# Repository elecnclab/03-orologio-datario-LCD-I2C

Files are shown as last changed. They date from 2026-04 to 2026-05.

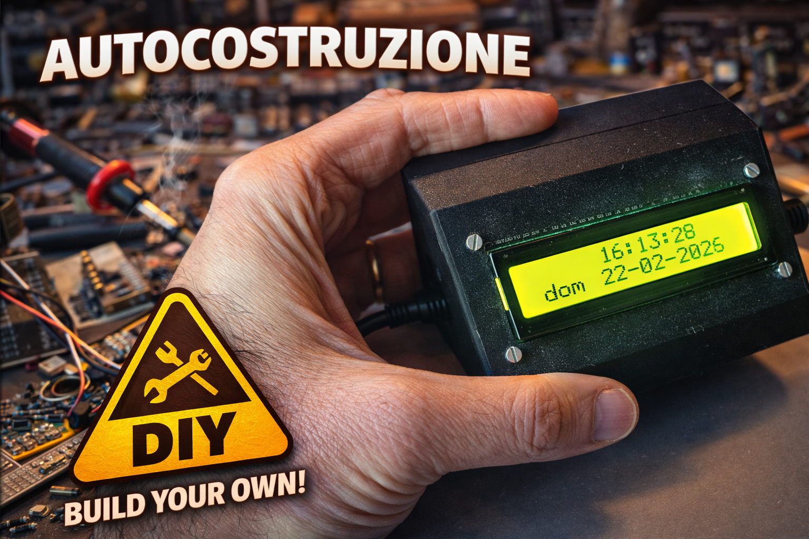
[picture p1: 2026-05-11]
media/foto/miniatura-1.png

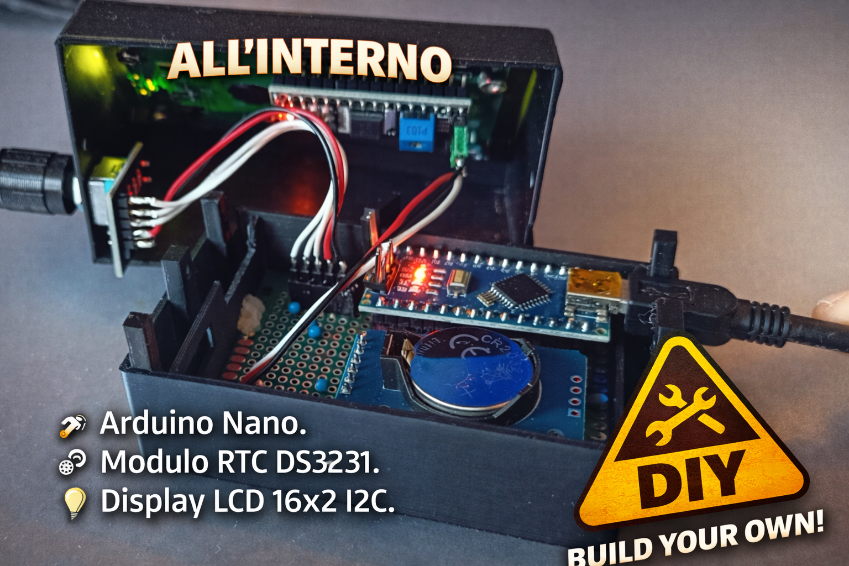
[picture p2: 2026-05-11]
media/foto/miniatura-2.png

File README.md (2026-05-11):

# 03-orologio-datario-LCD-I2C

Orologio digitale multifunzione con datario, timer countdown, cronometro e sveglia giornaliera.
Il progetto usa `Arduino Nano`, `RTC DS3231`, `LCD 16x2 I2C`, encoder rotativo (`KY-040`) e buzzer attivo LOW.

Video demo: https://youtu.be/ws_6DP3VXj8

## Caratteristiche principali

- Visualizzazione ora (`HH:MM:SS`) con allineamento configurabile (`SX`, `CTR`, `DX`)
- Datario con giorno settimana in italiano (`dom`...`sab`)
- Impostazione ora e data da menu
- Timer countdown (`00:00:00` a `99:59:59`) con pausa/riprendi
- Cronometro con visualizzazione `MM:SS:CC`
- Sveglia giornaliera basata su interrupt hardware DS3231 (pin `INT/SQW`)
- Parametri persistenti in EEPROM:
  - retroilluminazione LCD
  - allineamento ora
  - stato sveglia e orario sveglia

## Hardware

- Arduino Nano (ATmega328P)
- Modulo RTC DS3231
- Display LCD 16x2 con backpack I2C (indirizzo firmware: `0x27`)
- Encoder rotativo KY-040 con pulsante integrato
- Buzzer attivo LOW

## Collegamenti

### Encoder KY-040

- `CLK` -> `D4`
- `DT` -> `D3`
- `SW` -> `D2`
- `+` -> `5V`
- `GND` -> `GND`

### Bus I2C (LCD + DS3231)

- `SDA` -> `A4`
- `SCL` -> `A5`
- `VCC` -> `5V`
- `GND` -> `GND`

### Buzzer attivo LOW

- `IN` -> `D6`
- `GND` -> `GND`

### Interrupt sveglia DS3231

- `INT/SQW` -> `D7`

## Librerie Arduino usate

- `Wire.h`
- `RTClib.h`
- `LiquidCrystal_I2C.h`
- `EEPROM.h`

## Struttura repository

- `.github/`
- `firmware/03-orologio-datario-LCD-I2C/03-orologio-datario-LCD-I2C.ino`
- `docs/bom/`
- `docs/schemi/`
- `docs/note-tecniche/`
- `media/foto/`
- `media/github-images/`
- `hardware/stl/`
- `CHANGELOG.md`
- `VERSION`

## Media

- Foto progetto: `media/foto/miniatura-1.png`, `media/foto/miniatura-2.png`
- Immagini per README/GitHub: `media/github-images/`

## File STL

- `hardware/stl/base-orologio.stl`
- `hardware/stl/front-orologio.stl`

## Compilazione e upload

1. Apri lo sketch in Arduino IDE:
   - `firmware/03-orologio-datario-LCD-I2C/03-orologio-datario-LCD-I2C.ino`
2. Verifica/installa le librerie richieste.
3. Se necessario, adatta:
   - indirizzo I2C LCD (`LCD_ADDR`, default `0x27`)
   - verso encoder (`ENCODER_DIRECTION`, default `+1`)
4. Seleziona scheda e porta corrette.
5. Compila e carica.

## Uso rapido interfaccia

- **RUN (schermata normale)**
  - Rotazione encoder: apre `PARAM/INFO`
  - Pressione lunga: apre `MENU` principale

- **MENU principale**
  - Voci: `ORA`, `DATA`, `TIMER`, `SVEGLIA`, `CRONOMETRO`
  - Rotazione: cambia voce
  - Click: entra/modifica
  - Pressione lunga: ritorna a `RUN`

Per il dettaglio completo della logica stati e comandi:
- `docs/note-tecniche/architettura-firmware.md`
- `docs/note-tecniche/mappa-menu-e-comandi.md`

## Note operative

- Alla prima accensione, se RTC ha perso alimentazione, l'orario viene impostato alla data/ora di compilazione firmware.
- La riga data su LCD mostra 15 caratteri + icona campanella (se sveglia attiva) nell'ultimo carattere.
- Nel menu `PARAM/INFO` la voce `RESET SETTINGS` e' presente ma non implementata (volutamente lasciata vuota nel firmware attuale).

## Stato progetto

Firmware funzionante e testato fisicamente su hardware reale.
Documentazione tecnica in aggiornamento incrementale in `docs/note-tecniche/`.

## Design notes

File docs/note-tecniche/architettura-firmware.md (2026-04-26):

# Architettura firmware

## Panoramica

Il firmware e' implementato come macchina a stati finiti (`enum Mode`) con loop non bloccante.
Le funzionalita' principali convivono senza `delay()` operativo (tranne splash iniziale), usando `millis()` per refresh display, blink campi e gestione buzzer.

File sorgente:
- `firmware/03-orologio-datario-LCD-I2C/03-orologio-datario-LCD-I2C.ino`

## Moduli logici principali

- **RTC DS3231**
  - lettura data/ora corrente (`rtc.now()`)
  - set ora/data (`rtc.adjust(...)`)
  - gestione sveglia giornaliera con Alarm1

- **Display LCD 16x2 I2C**
  - rendering pagine UI per ogni stato
  - buffering per ridurre sfarfallio (`lcdPrintLineBuffered`)
  - carattere custom campanella in posizione finale riga 2

- **Input encoder + pulsante**
  - quadratura encoder con interrupt `PCINT2_vect` su D3/D4
  - accumulo delta e riduzione rumore tramite `readEncDeltaAtomic()`
  - eventi pulsante: click corto / pressione lunga (`LONG_PRESS_MS = 1000`)

- **Buzzer attivo LOW**
  - beep non bloccante con timeout (`buzzerStart`, `buzzerUpdate`)
  - sequenza sveglia con lampeggio retroilluminazione (`alarmBeepSequenceUpdate`)

- **Persistenza EEPROM**
  - inizializzazione con magic byte (`0xA5`)
  - salvataggio impostazioni utente e sveglia

## Macchina a stati (`Mode`)

Stati definiti:
- `RUN`
- `MENU`
- `SET_TIME`
- `SET_DATE`
- `SET_TIMER`
- `TIMER_RUNNING`
- `PARAM_MENU`
- `ALARM_MENU`
- `SET_ALARM`
- `STOPWATCH_RUNNING`

Approccio:
- ogni stato gestisce input (`step`, `evtShortClick`, `evtLongPress`)
- rendering periodico vincolato da `REFRESH_MS`
- transizioni esplicite tramite funzioni `enter...()`

## Temporizzazioni principali

- `REFRESH_MS = 120` ms: refresh display/UI
- `BLINK_MS = 350` ms: lampeggio campo in edit
- `PARAM_TIMEOUT_MS = 8000` ms: uscita automatica da `PARAM_MENU`
- `LONG_PRESS_MS = 1000` ms: soglia pressione lunga pulsante encoder

## Gestione sveglia DS3231

- Il pin `INT/SQW` del DS3231 e' collegato a `D7` (`ALARM_PIN`).
- In setup:
  - disattivazione square wave
  - pulizia flag allarmi
  - programmazione Alarm1 giornaliera su `alarmHour:alarmMin:00`
- In loop:
  - polling livello pin (`LOW` = evento sveglia)
  - avvio sequenza beep
  - clear flag Alarm1

## Timer countdown

- Set da menu (`HH:MM:SS`, max 99 ore)
- Start solo se durata > 0
- In esecuzione:
  - click corto: pausa/riprendi
  - pressione lunga: stop/uscita
- A fine timer:
  - beep 500 ms
  - messaggio `TIMER SCADUTO` per circa 2 s

## Cronometro

- Base tempo: `millis()`
- Stati logici: fermo / running / pausa
- Click corto: start-pause-resume
- Pressione lunga: reset + uscita a `RUN`
- Formato visualizzato: `MM:SS:CC`

## EEPROM: mappa indirizzi

- `0`: magic byte
- `1`: backlight (`0/1`)
- `2`: allineamento orario (`0..2`)
- `3`: sveglia abilitata (`0/1`)
- `4`: ora sveglia (`0..23`)
- `5`: minuti sveglia (`0..59`)

Nota: la voce `RESET SETTINGS` e' prevista in UI ma la logica e' volutamente non implementata nel firmware attuale.

## Pinout firmware (riepilogo)

- Encoder `CLK` -> `D4`
- Encoder `DT` -> `D3`
- Encoder `SW` -> `D2`
- Buzzer -> `D6` (attivo LOW)
- DS3231 `INT/SQW` -> `D7`
- I2C -> `A4 SDA`, `A5 SCL`

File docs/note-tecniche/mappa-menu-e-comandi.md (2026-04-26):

# Mappa menu e comandi encoder

Questa nota descrive il comportamento dell'interfaccia utente nel firmware attuale.

## Convenzioni input

- **Rotazione encoder**: incrementa/decrementa valore o selezione menu
- **Click corto**: conferma / entra nel campo successivo / toggle funzione
- **Pressione lunga** (~1 s): uscita o ritorno al livello precedente

## Stato RUN

Schermata standard:
- Riga 1: ora (`HH:MM:SS`) con allineamento configurabile
- Riga 2: `giorno dd-mm-yyyy` + campanella se sveglia attiva

Comandi:
- Rotazione -> entra in `PARAM_MENU`
- Pressione lunga -> entra in `MENU`

## MENU principale

Voci in ordine:
1. `ORA`
2. `DATA`
3. `TIMER`
4. `SVEGLIA`
5. `CRONOMETRO`

Comandi:
- Rotazione -> cambia voce
- Click corto -> entra nella voce selezionata
- Pressione lunga -> ritorna a `RUN`

## SET ORA (`SET_TIME`)

Campi editabili in sequenza:
1. ore
2. minuti
3. secondi

Comandi:
- Rotazione -> modifica campo corrente (con wrap)
- Click corto -> campo successivo; sull'ultimo campo salva su RTC e torna a `RUN`
- Pressione lunga -> annulla/uscita a `RUN`

## SET DATA (`SET_DATE`)

Campi editabili in sequenza:
1. giorno
2. mese
3. anno (2000..2099)

Comandi:
- Rotazione -> modifica campo corrente (con wrap)
- Click corto -> campo successivo; sull'ultimo campo salva su RTC e torna a `RUN`
- Pressione lunga -> annulla/uscita a `RUN`

Note:
- I limiti del giorno sono coerenti con mese/anno (anni bisestili inclusi).

## SET TIMER (`SET_TIMER`)

Campi editabili in sequenza:
1. ore (0..99)
2. minuti (0..59)
3. secondi (0..59)

Comandi:
- Rotazione -> modifica campo corrente
- Click corto -> campo successivo; sull'ultimo campo avvia countdown (se diverso da zero)
- Pressione lunga -> uscita a `RUN`

## TIMER in esecuzione (`TIMER_RUNNING`)

Visualizzazione:
- Riga 1: orario corrente
- Riga 2: `TIMER HH:MM:SS` oppure `PAUSA HH:MM:SS`

Comandi:
- Click corto -> pausa/riprendi
- Pressione lunga -> stop timer e ritorno a `RUN`

Fine timer:
- beep breve
- messaggio `TIMER SCADUTO`
- ritorno automatico a `RUN`

## Menu parametri/info (`PARAM_MENU`)

Accesso da `RUN` ruotando l'encoder.
Timeout automatico: circa 8 s senza azioni.

Voci:
1. `BACKLIGHT: ON/OFF` (toggle + salvataggio EEPROM)
2. `ORARIO: SX/CTR/DX` (ciclo + salvataggio EEPROM)
3. `TEST BUZZER` (beep 1 s)
4. `INFO FW` (pagina info)
5. `RESET SETTINGS` (placeholder non attivo)

Comandi:
- Rotazione -> cambia voce
- Click corto -> esegue azione voce
- Pressione lunga -> ritorna a `RUN`

In `INFO FW`:
- Click corto o pressione lunga -> ritorno a lista `PARAM_MENU`

## Menu sveglia (`ALARM_MENU`)

Voci:
1. `ATTIVA: ON/OFF`
2. `ORA: HH:MM`

Comandi:
- Rotazione -> seleziona voce
- Click corto su `ATTIVA` -> toggle + salva EEPROM + riprogramma DS3231
- Click corto su `ORA` -> entra in `SET_ALARM`
- Pressione lunga -> ritorna a `RUN`

## SET SVEGLIA (`SET_ALARM`)

Campi editabili:
1. ore
2. minuti

Comandi:
- Rotazione -> modifica campo
- Click corto -> passa al campo successivo; a fine sequenza salva e torna a `ALARM_MENU`
- Pressione lunga -> ritorna a `ALARM_MENU` senza conferma finale

## CRONOMETRO (`STOPWATCH_RUNNING`)

Visualizzazione:
- Riga 1: orario corrente
- Riga 2: `CRONO MM:SS:CC` oppure `PAUSA MM:SS:CC`

Comandi:
- Click corto -> start/pause/resume
- Pressione lunga -> reset cronometro e ritorno a `RUN`

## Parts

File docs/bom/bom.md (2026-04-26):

# BOM (Bill of Materials)

Elenco componenti principali del progetto `03-orologio-datario-LCD-I2C`.

## Elettronica

| Qta | Componente | Note |
|---|---|---|
| 1 | Arduino Nano (ATmega328P) | Compatibile 5V |
| 1 | RTC DS3231 | Modulo I2C |
| 1 | LCD 16x2 I2C | Backpack tipico PCF8574, indirizzo firmware `0x27` |
| 1 | Encoder KY-040 | Con pulsante integrato |
| 1 | Buzzer attivo LOW | Pilotato da `D6` |

## Cablaggio rapido

- I2C: `A4` (SDA), `A5` (SCL)
- Encoder: `D4` (CLK), `D3` (DT), `D2` (SW)
- Sveglia DS3231: `INT/SQW` su `D7`
- Buzzer: `IN` su `D6`

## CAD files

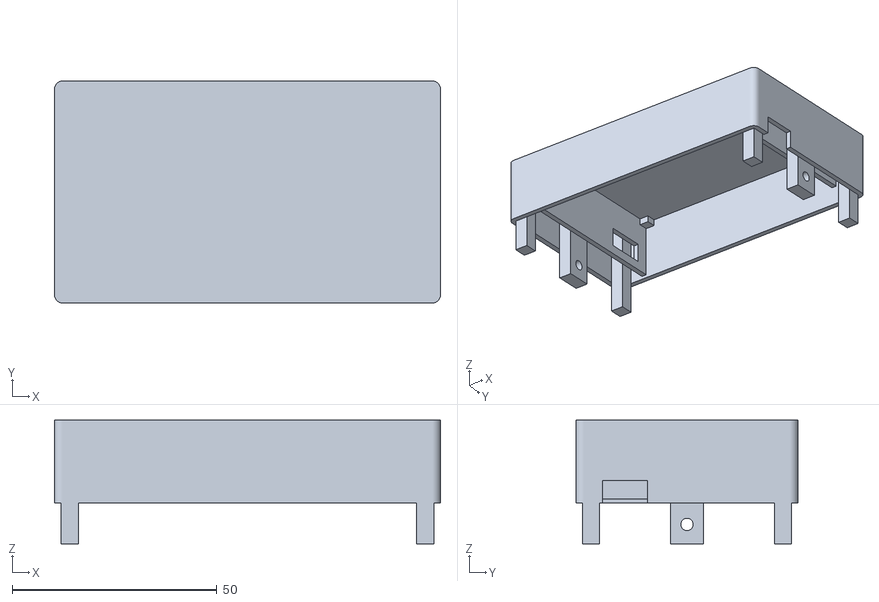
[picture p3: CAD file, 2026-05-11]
hardware/stl/base-orologio.stl
94.2 x 54.2 x 30.2

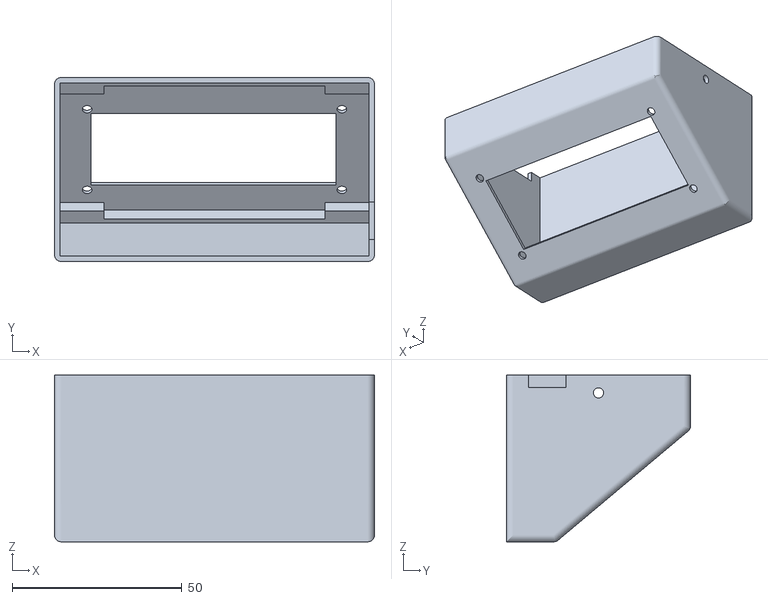
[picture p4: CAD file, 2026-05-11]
hardware/stl/front-orologio.stl
94.2 x 54.2 x 49.0

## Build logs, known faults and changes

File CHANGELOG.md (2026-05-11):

# Changelog

Tutte le modifiche rilevanti a questo progetto sono documentate in questo file.

## [1.0.1] - 2026-05-11

### Added

- File STL:
  - `hardware/stl/base-orologio.stl`
  - `hardware/stl/front-orologio.stl`
- Foto progetto:
  - `media/foto/miniatura-1.png`
  - `media/foto/miniatura-2.png`

### Changed

- `README.md` aggiornato con sezione media e file STL

## [1.0.0] - 2026-04-26

### Added

- Struttura base repository (`firmware`, `docs`, `media`, `hardware`)
- README iniziale
- Note tecniche:
  - architettura firmware
  - mappa menu e comandi encoder
- Sezione `docs/bom/` con BOM iniziale
- Template PR in `.github/pull_request_template.md`

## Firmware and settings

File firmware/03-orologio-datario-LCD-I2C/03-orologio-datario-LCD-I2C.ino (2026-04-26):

/*
   ------------------------------------------------------------
   Orologio Multifuzione con Datario - V2
   Arduino Nano + RTC DS3231 + LCD 16x2 I2C
   ------------------------------------------------------------

   Breve descrizione:
   Orologio digitale multifunzione con visualizzazione di ora,
   data e giorno della settimana, dotato di timer countdown,
   cronometro, sveglia giornaliera e menu di navigazione tramite
   encoder rotativo. Il dispositivo utilizza un modulo RTC
   DS3231 per mantenere l'orario con elevata precisione e un
   buzzer attivo per le segnalazioni acustiche.

   Video del progetto:
   https://youtu.be/ws_6DP3VXj8

   Autore:
   Giuseppe Romano

   Canale YouTube:
   Electronic & CNC Lab
   https://www.youtube.com/@Electronic.CNCLab

   ------------------------------------------------------------
   Progetto realizzato a scopo didattico e divulgativo.
   ------------------------------------------------------------
*/

#include <Wire.h>
#include <RTClib.h>
#include <LiquidCrystal_I2C.h>
#include <EEPROM.h>

/*
  Orologio + Datario + Timer + Sveglia giornaliera
  RTC: DS3231
  LCD: 16x2 I2C
  Encoder: KY-040
  Buzzer: attivo LOW

  Collegamenti:
    Encoder CLK -> D4
    Encoder DT  -> D3
    Encoder SW  -> D2
    Encoder +   -> 5V
    Encoder GND -> GND

    LCD I2C / DS3231:
      SDA -> A4
      SCL -> A5
      VCC -> 5V
      GND -> GND

    Buzzer attivo LOW:
      IN  -> D6
      GND -> GND

    DS3231 INT/SQW -> D7
*/

#define PIN_ENC_CLK 4
#define PIN_ENC_DT 3
#define PIN_ENC_SW 2

#define BUZZER_PIN 6  // buzzer attivo LOW
#define ALARM_PIN 7   // DS3231 INT/SQW -> LOW quando scatta la sveglia

#define LCD_ADDR 0x27
#define LCD_COLS 16
#define LCD_ROWS 2


const unsigned long LONG_PRESS_MS = 1000;
const int ENCODER_DIRECTION = +1;

const unsigned long REFRESH_MS = 120;
const unsigned long BLINK_MS = 350;
const unsigned long PARAM_TIMEOUT_MS = 8000;

bool inInfoFw = false;

RTC_DS3231 rtc;
LiquidCrystal_I2C lcd(LCD_ADDR, LCD_COLS, LCD_ROWS);

const char *giorniITA[7] = { "dom", "lun", "mar", "mer", "gio", "ven", "sab" };

byte bellChar[8] = {
  B00100,
  B01110,
  B01110,
  B01110,
  B11111,
  B00100,
  B00000,
  B00100
};



// ------------------- STATI -------------------
enum Mode {
  RUN,
  MENU,
  SET_TIME,
  SET_DATE,
  SET_TIMER,
  TIMER_RUNNING,
  PARAM_MENU,
  ALARM_MENU,
  SET_ALARM,
  STOPWATCH_RUNNING
};

Mode mode = RUN;

// ------------------- PARAMETRI RUN -------------------
enum TimeAlign : uint8_t { ALIGN_LEFT = 0,
                           ALIGN_CENTER = 1,
                           ALIGN_RIGHT = 2 };
TimeAlign timeAlign = ALIGN_CENTER;

bool backlightEnabled = true;

// ------------------- SVEGLIA -------------------
bool alarmEnabled = false;
uint8_t alarmHour = 7;
uint8_t alarmMin = 30;

// ------------------- TIMER -------------------
uint8_t timerSetH = 0;
uint8_t timerSetM = 0;
uint8_t timerSetS = 0;

bool timerActive = false;
uint32_t timerDurationSec = 0;
unsigned long timerEndMillis = 0;
bool timerBeepDone = false;
unsigned long timerBeepShownAt = 0;
bool timerPaused = false;
uint32_t timerRemainingSec = 0;

// ------------------- CRONOMETRO -------------------
bool stopwatchRunning = false;
bool stopwatchPaused = false;
unsigned long stopwatchStartMillis = 0;
unsigned long stopwatchAccumulatedMs = 0;

// ------------------- MENU INDEX -------------------
int menuIndex = 0;       // MENU principale
int paramIndex = 0;      // PARAM_MENU
int alarmMenuIndex = 0;  // ALARM_MENU

// ------------------- EDITING -------------------
int setHour, setMin, setSec;
int setDay, setMonth, setYear;
int fieldIndex = 0;  // TIME/DATE/TIMER/ALARM

uint8_t setAlarmHour, setAlarmMin;

// ------------------- BLINK -------------------
unsigned long lastBlinkToggle = 0;
bool blinkOn = true;

// ------------------- REFRESH -------------------
unsigned long lastRefresh = 0;
unsigned long paramLastAction = 0;

// ------------------- BUTTON EVENTS -------------------
bool btnPressed = false;
bool btnPrevPressed = false;
unsigned long btnPressStart = 0;
bool longPressFired = false;
bool evtShortClick = false;
bool evtLongPress = false;

// ------------------- ENCODER PCINT -------------------
volatile int16_t encDelta = 0;
volatile uint8_t encPrevPins = 0;

// ------------------- BUZZER NON BLOCCANTE -------------------
bool buzzerActive = false;
unsigned long buzzerOffAt = 0;
bool alarmBeepSequenceActive = false;
uint8_t alarmBeepCount = 0;
bool alarmBeepPhaseOn = false;
unsigned long alarmBeepNextMs = 0;

// ------------------- EEPROM -------------------
const int EEPROM_ADDR_MAGIC = 0;
const int EEPROM_ADDR_BACKLIGHT = 1;
const int EEPROM_ADDR_ALIGN = 2;
const int EEPROM_ADDR_ALARM_EN = 3;
const int EEPROM_ADDR_ALARM_HH = 4;
const int EEPROM_ADDR_ALARM_MM = 5;
const uint8_t EEPROM_MAGIC = 0xA5;

// ------------------- UTIL -------------------
String twoDigits(int v) {
  if (v < 10) return "0" + String(v);
  return String(v);
}

void clearLine(uint8_t row) {
  lcd.setCursor(0, row);
  for (int i = 0; i < LCD_COLS; i++) lcd.print(" ");
}

String pad16(const String &s) {
  if ((int)s.length() >= LCD_COLS) return s.substring(0, LCD_COLS);
  String out = s;
  while ((int)out.length() < LCD_COLS) out += ' ';
  return out;
}

String lastLine0 = "";
String lastLine1 = "";

void lcdPrintLineBuffered(uint8_t row, const String &s) {
  String p = pad16(s);

  if (row == 0) {
    if (p == lastLine0) return;
    lastLine0 = p;
  } else {
    if (p == lastLine1) return;
    lastLine1 = p;
  }

  lcd.setCursor(0, row);
  lcd.print(p);
}

int wrapInt(int value, int minV, int maxV) {
  if (value < minV) return maxV;
  if (value > maxV) return minV;
  return value;
}

bool isLeap(int y) {
  return ((y % 4 == 0 && y % 100 != 0) || (y % 400 == 0));
}

int daysInMonth(int y, int m) {
  if (m == 2) return isLeap(y) ? 29 : 28;
  if (m == 4 || m == 6 || m == 9 || m == 11) return 30;
  return 31;
}

void blankRange(String &s, int start, int len) {
  for (int i = 0; i < len; i++) {
    int idx = start + i;
    if (idx >= 0 && idx < (int)s.length()) s.setCharAt(idx, ' ');
  }
}

String onOff(bool v) {
  return v ? "ON" : "OFF";
}

String alignToStr(TimeAlign a) {
  switch (a) {
    case ALIGN_LEFT: return "SX";
    case ALIGN_CENTER: return "CTR";
    case ALIGN_RIGHT: return "DX";
    default: return "SX";
  }
}

void updateBlink() {
  if (millis() - lastBlinkToggle >= BLINK_MS) {
    lastBlinkToggle = millis();
    blinkOn = !blinkOn;
  }
}

void resetBlink() {
  blinkOn = true;
  lastBlinkToggle = millis();
}

// ------------------- EEPROM -------------------
void loadSettingsFromEEPROM() {
  uint8_t magic = EEPROM.read(EEPROM_ADDR_MAGIC);

  if (magic != EEPROM_MAGIC) {
    backlightEnabled = true;
    timeAlign = ALIGN_CENTER;
    alarmEnabled = false;
    alarmHour = 7;
    alarmMin = 30;

    EEPROM.update(EEPROM_ADDR_MAGIC, EEPROM_MAGIC);
    EEPROM.update(EEPROM_ADDR_BACKLIGHT, (uint8_t)backlightEnabled);
    EEPROM.update(EEPROM_ADDR_ALIGN, (uint8_t)timeAlign);
    EEPROM.update(EEPROM_ADDR_ALARM_EN, (uint8_t)alarmEnabled);
    EEPROM.update(EEPROM_ADDR_ALARM_HH, alarmHour);
    EEPROM.update(EEPROM_ADDR_ALARM_MM, alarmMin);
    return;
  }

  backlightEnabled = (EEPROM.read(EEPROM_ADDR_BACKLIGHT) != 0);

  uint8_t a = EEPROM.read(EEPROM_ADDR_ALIGN);
  if (a > ALIGN_RIGHT) a = ALIGN_LEFT;
  timeAlign = (TimeAlign)a;

  alarmEnabled = (EEPROM.read(EEPROM_ADDR_ALARM_EN) != 0);
  alarmHour = EEPROM.read(EEPROM_ADDR_ALARM_HH);
  alarmMin = EEPROM.read(EEPROM_ADDR_ALARM_MM);

  if (alarmHour > 23) alarmHour = 7;
  if (alarmMin > 59) alarmMin = 30;
}

void saveSettingsToEEPROM() {
  EEPROM.update(EEPROM_ADDR_MAGIC, EEPROM_MAGIC);
  EEPROM.update(EEPROM_ADDR_BACKLIGHT, (uint8_t)backlightEnabled);
  EEPROM.update(EEPROM_ADDR_ALIGN, (uint8_t)timeAlign);
  EEPROM.update(EEPROM_ADDR_ALARM_EN, (uint8_t)alarmEnabled);
  EEPROM.update(EEPROM_ADDR_ALARM_HH, alarmHour);
  EEPROM.update(EEPROM_ADDR_ALARM_MM, alarmMin);
}

// ------------------- BACKLIGHT -------------------
void applyBacklight() {
  if (backlightEnabled) lcd.backlight();
  else lcd.noBacklight();
}

void setBacklightRaw(bool on) {
  if (on) lcd.backlight();
  else lcd.noBacklight();
}
// ------------------- BUZZER -------------------
void alarmBeepSequenceUpdate() {
  if (!alarmBeepSequenceActive) return;

  if ((long)(millis() - alarmBeepNextMs) < 0) return;

  if (!alarmBeepPhaseOn) {
    // Inizio beep
    digitalWrite(BUZZER_PIN, LOW);  // buzzer attivo LOW

    // Lampeggio display in sincronia col beep:
    // inverte lo stato normale della retroilluminazione
    setBacklightRaw(!backlightEnabled);

    alarmBeepPhaseOn = true;
    alarmBeepNextMs = millis() + 300;  // beep ON per 300 ms
  } else {
    // Fine beep
    digitalWrite(BUZZER_PIN, HIGH);  // buzzer spento

    // Ripristina lo stato normale impostato dall'utente
    applyBacklight();

    alarmBeepPhaseOn = false;
    alarmBeepCount++;

    if (alarmBeepCount >= 5) {
      alarmBeepSequenceActive = false;

      // Sicurezza finale: ripristina la retroilluminazione corretta
      applyBacklight();
    } else {
      alarmBeepNextMs = millis() + 300;  // pausa 300 ms
    }
  }
}

void buzzerStart(unsigned long durationMs) {
  digitalWrite(BUZZER_PIN, LOW);  // attivo LOW
  buzzerActive = true;
  buzzerOffAt = millis() + durationMs;
}

void buzzerUpdate() {
  if (buzzerActive && (long)(millis() - buzzerOffAt) >= 0) {
    digitalWrite(BUZZER_PIN, HIGH);  // spento
    buzzerActive = false;
  }
}

void beepTimerEnd() {
  buzzerStart(500);
}

void beepAlarmDaily() {
  alarmBeepSequenceActive = true;
  alarmBeepCount = 0;
  alarmBeepPhaseOn = false;
  alarmBeepNextMs = millis();
}

// ------------------- DS3231 ALARM -------------------
void disableDailyAlarmDS3231() {
  rtc.disableAlarm(1);
  rtc.clearAlarm(1);
}

void programDailyAlarmDS3231() {
  // Spegni square wave e pulisci eventuali flag
  rtc.writeSqwPinMode(DS3231_OFF);
  rtc.clearAlarm(1);
  rtc.clearAlarm(2);
  rtc.disableAlarm(1);
  rtc.disableAlarm(2);

  if (!alarmEnabled) return;

  // Alarm1 giornaliera su HH:MM:SS = alarmHour:alarmMin:00
  // Con DS3231_A1_Hour la data viene ignorata, l'orario viene confrontato ogni giorno
  rtc.setAlarm1(
    DateTime(2000, 1, 1, alarmHour, alarmMin, 0),
    DS3231_A1_Hour);

  rtc.clearAlarm(1);
}

void handleAlarmInterruptIfAny() {
  if (!alarmEnabled) return;

  if (digitalRead(ALARM_PIN) == LOW) {
    beepAlarmDaily();
    rtc.clearAlarm(1);
  }
}

// ------------------- DISPLAY -------------------
void showRun() {
  DateTime now = rtc.now();

  String timeStr = twoDigits(now.hour()) + ":" + twoDigits(now.minute()) + ":" + twoDigits(now.second());
  int padLeft = 0;
  if (timeAlign == ALIGN_CENTER) padLeft = (LCD_COLS - 8) / 2;
  else if (timeAlign == ALIGN_RIGHT) padLeft = (LCD_COLS - 8);

  String r1 = "";
  for (int i = 0; i < padLeft; i++) r1 += " ";
  r1 += timeStr;

  int dow = now.dayOfTheWeek();
  String r2 = String(giorniITA[dow]) + " " + twoDigits(now.day()) + "-" + twoDigits(now.month()) + "-" + String(now.year());

  r2 = pad16(r2);

  lcdPrintLineBuffered(0, r1);

  // Riga 2 scritta direttamente
  lcd.setCursor(0, 1);
  lcd.print(r2.substring(0, 15));  // primi 15 caratteri

  if (alarmEnabled) {
    lcd.write(byte(0));  // campanella
  } else {
    lcd.print(" ");
  }

  lastLine1 = r2;  // opzionale, per non perdere coerenza col buffering
}

void showMenu() {
  String l0 = "MENU";
  String l1;

  switch (menuIndex) {
    case 0: l1 = ">ORA"; break;
    case 1: l1 = ">DATA"; break;
    case 2: l1 = ">TIMER"; break;
    case 3: l1 = ">SVEGLIA"; break;
    case 4: l1 = ">CRONOMETRO"; break;
    default: l1 = ">ORA"; break;
  }

  lcdPrintLineBuffered(0, l0);
  lcdPrintLineBuffered(1, l1);
}

void showParamMenu() {
  String l0 = "PARAM/INFO";
  String l1;

  switch (paramIndex) {

    case 0:
      l1 = String(">BACKLIGHT:") + onOff(backlightEnabled);
      break;

    case 1:
      l1 = String(">ORARIO:") + alignToStr(timeAlign);
      break;

    case 2:
      l1 = ">TEST BUZZER";
      break;

    case 3:
      l1 = ">INFO FW";
      break;

    case 4:
      l1 = ">RESET SETTINGS";
      break;

    default:
      l1 = ">-";
      break;
  }

  lcdPrintLineBuffered(0, l0);
  lcdPrintLineBuffered(1, l1);
}

void showAlarmMenu() {
  String l0 = "SVEGLIA";
  String l1;

  switch (alarmMenuIndex) {
    case 0:
      l1 = String(">ATTIVA:") + onOff(alarmEnabled);
      break;

    case 1:
      l1 = String(">ORA:") + twoDigits(alarmHour) + ":" + twoDigits(alarmMin);
      break;

    default:
      l1 = ">ATTIVA";
      break;
  }

  lcdPrintLineBuffered(0, l0);
  lcdPrintLineBuffered(1, l1);
}

void showSetTime() {
  updateBlink();

  String r1 = "SET ORA";
  String r2 = twoDigits(setHour) + ":" + twoDigits(setMin) + ":" + twoDigits(setSec);

  if (!blinkOn) {
    if (fieldIndex == 0) blankRange(r2, 0, 2);
    if (fieldIndex == 1) blankRange(r2, 3, 2);
    if (fieldIndex == 2) blankRange(r2, 6, 2);
  }

  lcdPrintLineBuffered(0, r1);
  lcdPrintLineBuffered(1, r2);
}

void showSetDate() {
  updateBlink();

  String r1 = "SET DATA";
  String r2 = twoDigits(setDay) + "-" + twoDigits(setMonth) + "-" + String(setYear);

  if (!blinkOn) {
    if (fieldIndex == 0) blankRange(r2, 0, 2);
    if (fieldIndex == 1) blankRange(r2, 3, 2);
    if (fieldIndex == 2) blankRange(r2, 6, 4);
  }

  lcdPrintLineBuffered(0, r1);
  lcdPrintLineBuffered(1, r2);
}
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
void loop() {
  updateButtonEvents();
  buzzerUpdate();
  alarmBeepSequenceUpdate();

  int step = (int)(ENCODER_DIRECTION * readEncDeltaAtomic());

  // Controllo sveglia hardware sempre attivo
  handleAlarmInterruptIfAny();

  switch (mode) {

    case RUN:
      if (evtLongPress) {
        enterMenu();
      }

      if (step != 0) {
        enterParamMenu();
        break;
      }

      if (millis() - lastRefresh >= REFRESH_MS) {
        lastRefresh = millis();
        showRun();
      }
      break;

    case MENU:
      if (step != 0) {
        int s = (step > 0) ? 1 : -1;
        menuIndex += s;
        if (menuIndex < 0) menuIndex = 4;
        if (menuIndex > 4) menuIndex = 0;
      }

      if (evtShortClick) {
        if (menuIndex == 0) enterSetTime();
        else if (menuIndex == 1) enterSetDate();
        else if (menuIndex == 2) enterSetTimer();
        else if (menuIndex == 3) enterAlarmMenu();
        else if (menuIndex == 4) enterStopwatch();
      }

      if (evtLongPress) mode = RUN;

      if (millis() - lastRefresh >= REFRESH_MS) {
        lastRefresh = millis();
        showMenu();
      }
      break;

    case SET_TIME:
      if (step != 0) {
        if (fieldIndex == 0) setHour = wrapInt(setHour + step, 0, 23);
        if (fieldIndex == 1) setMin = wrapInt(setMin + step, 0, 59);
        if (fieldIndex == 2) setSec = wrapInt(setSec + step, 0, 59);
      }

      if (evtShortClick) {
        if (fieldIndex < 2) {
          fieldIndex++;
          resetBlink();
        } else {
          saveTimeToRTC();
          mode = RUN;
        }
      }

      if (evtLongPress) mode = RUN;

      if (millis() - lastRefresh >= REFRESH_MS) {
        lastRefresh = millis();
        showSetTime();
      }
      break;

    case SET_DATE:
      if (step != 0) {
        if (fieldIndex == 0) {
          int dim = daysInMonth(setYear, setMonth);
          setDay = wrapInt(setDay + step, 1, dim);
        }

        if (fieldIndex == 1) {
          setMonth = wrapInt(setMonth + step, 1, 12);
          int dim = daysInMonth(setYear, setMonth);
          if (setDay > dim) setDay = dim;
        }

        if (fieldIndex == 2) {
          setYear += step;
          if (setYear < 2000) setYear = 2099;
          if (setYear > 2099) setYear = 2000;

          int dim = daysInMonth(setYear, setMonth);
          if (setDay > dim) setDay = dim;
        }
      }

      if (evtShortClick) {
        if (fieldIndex < 2) {
          fieldIndex++;
          resetBlink();
        } else {
          saveDateToRTC();
          mode = RUN;
        }
      }

      if (evtLongPress) mode = RUN;

      if (millis() - lastRefresh >= REFRESH_MS) {
        lastRefresh = millis();
        showSetDate();
      }
      break;

    case SET_TIMER:
      if (step != 0) {
        if (fieldIndex == 0) timerSetH = (uint8_t)wrapInt((int)timerSetH + step, 0, 99);
        if (fieldIndex == 1) timerSetM = (uint8_t)wrapInt((int)timerSetM + step, 0, 59);
        if (fieldIndex == 2) timerSetS = (uint8_t)wrapInt((int)timerSetS + step, 0, 59);
      }

      if (evtShortClick) {
        if (fieldIndex < 2) {
          fieldIndex++;
          resetBlink();
        } else {
          startTimerFromSet();
          resetBlink();
        }
      }

      if (evtLongPress) mode = RUN;

      if (millis() - lastRefresh >= REFRESH_MS) {
        lastRefresh = millis();
        showSetTimer();
      }
      break;

    case TIMER_RUNNING:
      {
        if (evtLongPress) {
          stopTimer();
          break;
        }

        if (evtShortClick) {
          if (timerPaused) resumeTimer();
          else pauseTimer();
        }

        unsigned long nowMs = millis();

        if (timerActive && !timerPaused) {
          if ((long)(nowMs - timerEndMillis) >= 0) {
            timerActive = false;
            timerRemainingSec = 0;

            if (!timerBeepDone) {
              beepTimerEnd();
              timerBeepDone = true;
              timerBeepShownAt = nowMs;
            }
          }
        }

        if (timerBeepDone) {
          showTimerExpired();
          if (nowMs - timerBeepShownAt > 2000UL) {
            mode = RUN;
          }
        } else {
          uint32_t remainingSec = 0;

          if (timerPaused) {
            remainingSec = timerRemainingSec;
          } else if (timerActive) {
            unsigned long msLeft = (unsigned long)(timerEndMillis - nowMs);
            remainingSec = (uint32_t)(msLeft / 1000UL);
          }

          if (millis() - lastRefresh >= REFRESH_MS) {
            lastRefresh = millis();
            showTimerRunning(remainingSec);
          }
        }
        break;
      }

case PARAM_MENU:
      if (millis() - paramLastAction > PARAM_TIMEOUT_MS) {
        exitParamMenu();
        break;
      }

      if (inInfoFw) {
        if (evtShortClick || evtLongPress) {
          inInfoFw = false;
          paramLastAction = millis();
          lastRefresh = 0;
        }

        if (millis() - lastRefresh >= REFRESH_MS) {
          lastRefresh = millis();
          lcdPrintLineBuffered(0, "FW v1.0");
          lcdPrintLineBuffered(1, "Electronic&CNC");
        }
        break;
      }

      if (step != 0) {
        paramLastAction = millis();
        int s = (step > 0) ? 1 : -1;
        paramIndex += s;

        const int maxIndex = 4;
        if (paramIndex < 0) paramIndex = maxIndex;
        if (paramIndex > maxIndex) paramIndex = 0;
      }

      if (evtShortClick) {
        paramLastAction = millis();

        if (paramIndex == 0) {
          backlightEnabled = !backlightEnabled;
          applyBacklight();
          saveSettingsToEEPROM();
        } else if (paramIndex == 1) {
          timeAlign = (TimeAlign)wrapInt((int)timeAlign + 1, (int)ALIGN_LEFT, (int)ALIGN_RIGHT);
          saveSettingsToEEPROM();
        } else if (paramIndex == 2) {
          buzzerStart(1000);  // TEST BUZZER: beep di 1 secondo
        } else if (paramIndex == 3) {
          inInfoFw = true;
          lastRefresh = 0;
        } else if (paramIndex == 4) {
          // RESET SETTINGS
          // anche questo per ora meglio lasciarlo vuoto,
          // poi aggiungiamo una conferma per non fare reset accidentali
        }
      }

      if (evtLongPress) {
        exitParamMenu();
      }

      if (millis() - lastRefresh >= REFRESH_MS) {
        lastRefresh = millis();
        showParamMenu();
      }
      break;

    case ALARM_MENU:
      if (step != 0) {
        int s = (step > 0) ? 1 : -1;
        alarmMenuIndex += s;
        if (alarmMenuIndex < 0) alarmMenuIndex = 1;
        if (alarmMenuIndex > 1) alarmMenuIndex = 0;
      }

      if (evtShortClick) {
        if (alarmMenuIndex == 0) {
          alarmEnabled = !alarmEnabled;
          saveSettingsToEEPROM();
          programDailyAlarmDS3231();
        } else if (alarmMenuIndex == 1) {
          enterSetAlarm();
        }
      }

      if (evtLongPress) mode = RUN;

      if (millis() - lastRefresh >= REFRESH_MS) {
        lastRefresh = millis();
        showAlarmMenu();
      }
      break;

    case SET_ALARM:
      if (step != 0) {
        if (fieldIndex == 0) setAlarmHour = (uint8_t)wrapInt((int)setAlarmHour + step, 0, 23);
        if (fieldIndex == 1) setAlarmMin = (uint8_t)wrapInt((int)setAlarmMin + step, 0, 59);
      }

      if (evtShortClick) {
        if (fieldIndex == 0) {
          fieldIndex = 1;
          resetBlink();
        } else {
          alarmHour = setAlarmHour;
          alarmMin = setAlarmMin;
          saveSettingsToEEPROM();
          programDailyAlarmDS3231();
          mode = ALARM_MENU;
        }
      }

      if (evtLongPress) mode = ALARM_MENU;

      if (millis() - lastRefresh >= REFRESH_MS) {
        lastRefresh = millis();
        showSetAlarm();
      }
      break;

    case STOPWATCH_RUNNING:
      if (evtShortClick) {
        if (stopwatchRunning) pauseStopwatch();
        else startStopwatch();
      }

      if (evtLongPress) {
        resetStopwatch();
        mode = RUN;
      }

      if (millis() - lastRefresh >= REFRESH_MS) {
        lastRefresh = millis();
        showStopwatch();
      }
      break;
  }
}

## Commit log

2026-04-26 docs: allinea struttura standard repo e aggiunge BOM/changelog
2026-05-11 docs(hw): aggiunge STL e foto progetto, aggiorna README/CHANGELOG
    [base-orologio.stl, front-orologio.stl]
